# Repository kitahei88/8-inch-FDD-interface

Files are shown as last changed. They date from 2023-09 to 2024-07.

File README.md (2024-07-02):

# ANSI 8 inch Floppy Disk Drive adapter and Power board
---
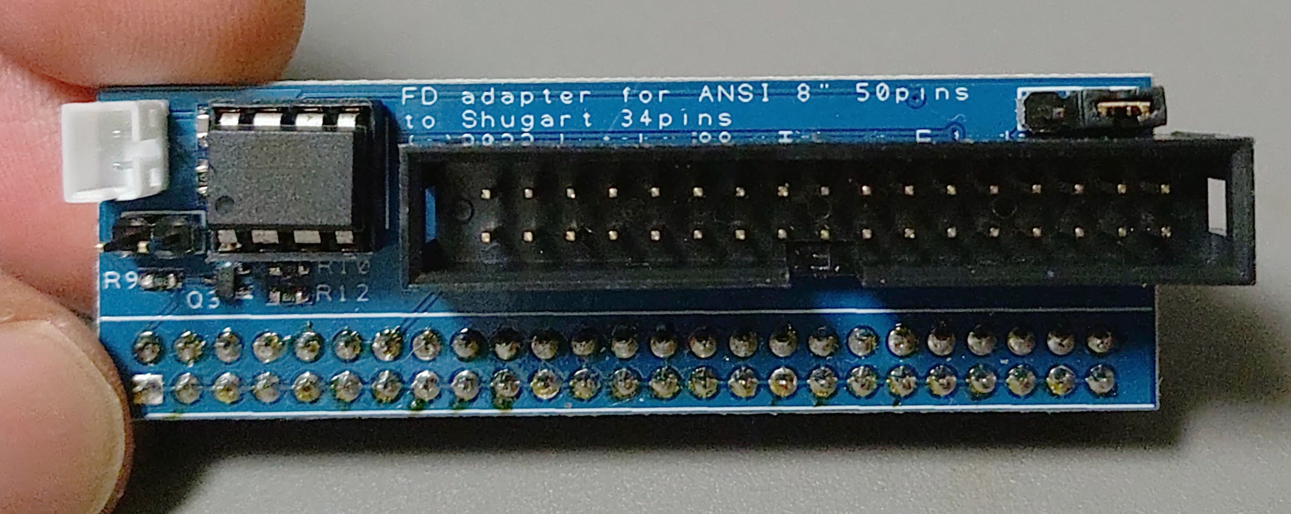
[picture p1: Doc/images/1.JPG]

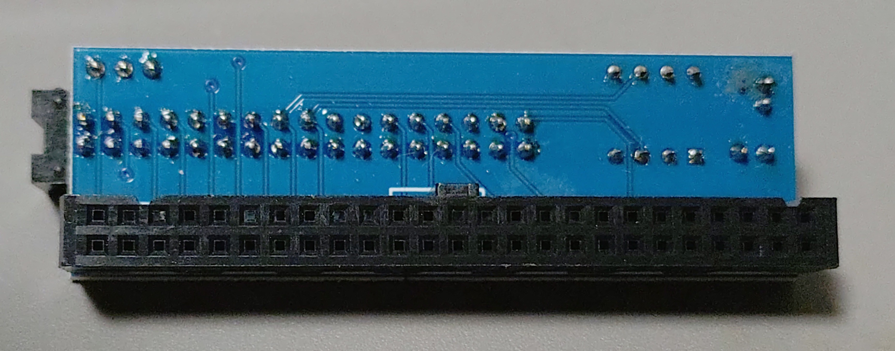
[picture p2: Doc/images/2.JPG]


This interface and power board is made for ANSI 8 inch interface drives and Pauline or any other FDD dump devices.
You can dump (or maybe write) 8 inch disk with this boards.
(And may be use with PC/AT machines that have FDD interfaces)

I tested NEC FD1165A and Pauline.

このインターフェースはANSI仕様の８インチドライブを通常の３４ピンコネクターに変換するものです。
このインターフェースを利用することで、Paulineやその他のフロッピーディスク読み出し環境で８インチディスクを読み込むことが可能となります。
ドライブに合わせたLowCurrent信号を作成することが出来ます。

NEC製のFD1165Aを利用して読み込み可能であることをテストしています。

Takuya Fukuda
Twitter: @kitahei88

License
This project is released under BSD 3-Clause License

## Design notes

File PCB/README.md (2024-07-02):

PCB was made with DesignSpark PCB Ver 10.0

Scheme is printed as PDF file.
Parts list is ODS file.

基板はDesignSpark PCB Ver10.0で作成しています。
gerberのフォルダにGerberとして出力しましています。それらをまとめたものもZIPファイルで置いてあります。
FusionPCBなどへ発注できると思います。

回路図はPDFファイルとしても参照可能です。
パーツリストは、ODSファイルに記載してあります。

The power supply board uses +24V DC power supply.
DC plug is an external diameter of 5.5 mm, an internal diameter of 2.1 mm, and a center-plus.
電源基板には+24Vの直流電源を使用します。
外形5.5mm、内径2.1mm、センタープラスのDCプラグで供給する形で作成しました。

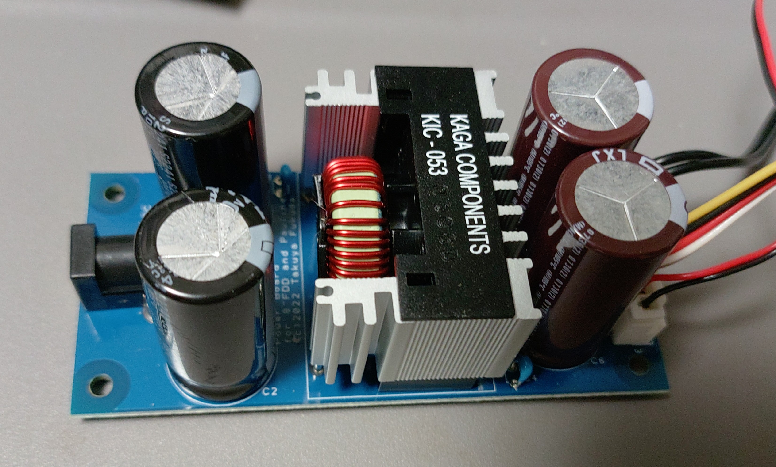
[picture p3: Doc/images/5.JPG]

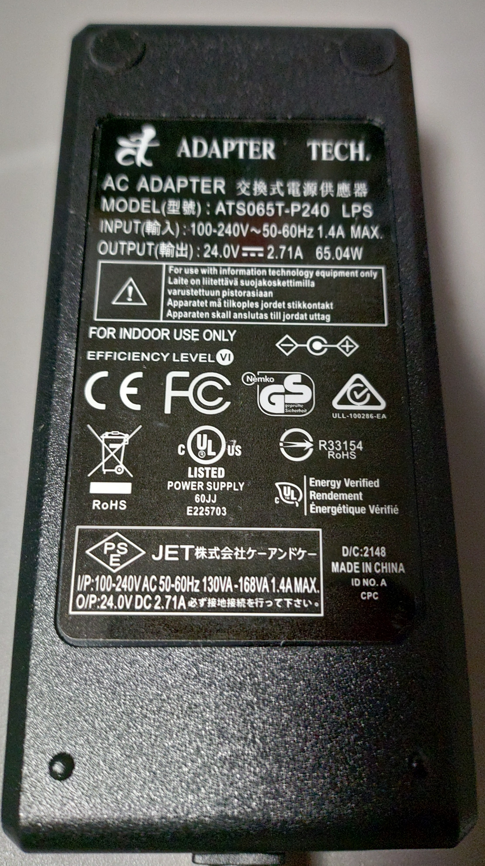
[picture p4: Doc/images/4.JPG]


The power outputs are XH 6pin connector for the 8" drive XH 2pin connector to supply power to the Pauline.
The output from each power supply pin is as shown in the image.

電源出力はXH6ピンが8インチドライブ用　XH2ピンがPaulineへの電源供給としています。
それぞれの電源ピンからの出力は画像に記載した通りです。

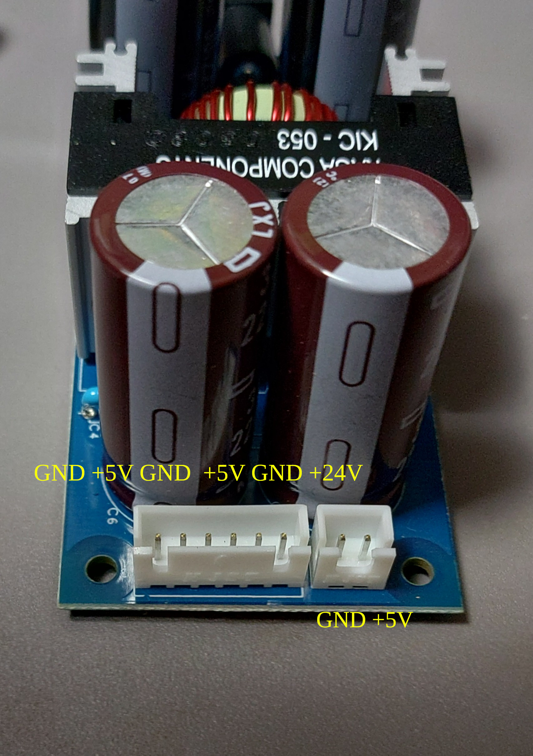
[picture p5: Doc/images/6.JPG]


One of the +5V from the XH6 pin feeds this interface board.
The interface side is made with a 2-pin PH connector.
The remaining +5V and +24V are supplied to the drive.
Refer to the data sheet of each drive for the connector to be supplied to the drive.

XH6ピンからの+5Vの一つはこのインターフェスに供給します。
インターフェス側はPHコネクターの2ピンのもので作成しています。
残りの+5V、+24Vはドライブへ供給します。
ドライブへのコネクターはそれぞれのドライブのデータシートなどを参考に供給してください。

NEC　FD1165Aの場合は、EIコネクターの7ピンで、
1pin +24V
2pin GND
3pin +5V
4pin GND
です。

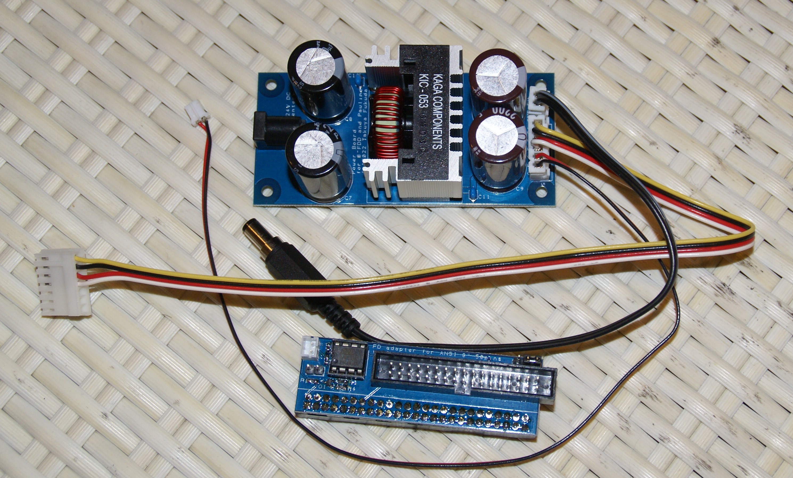
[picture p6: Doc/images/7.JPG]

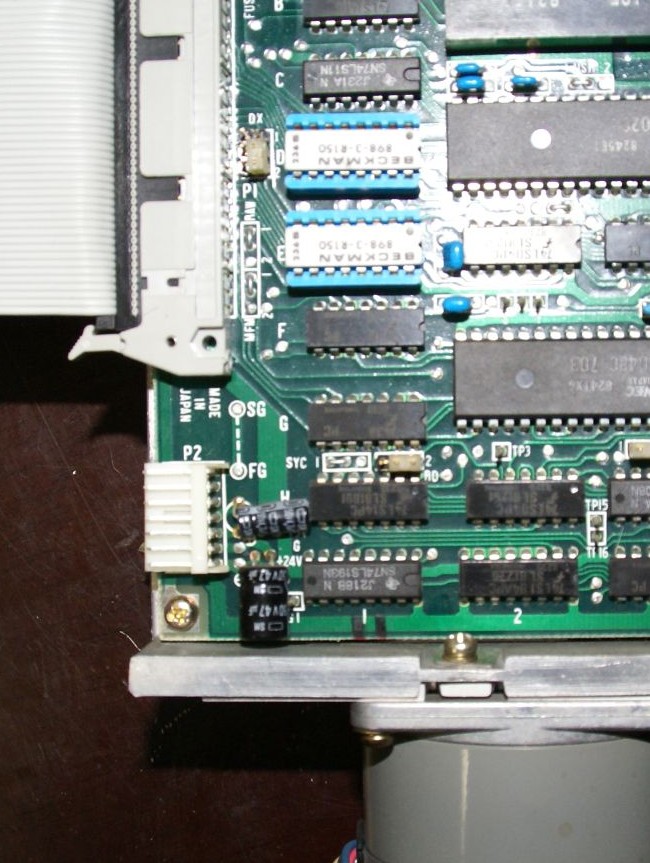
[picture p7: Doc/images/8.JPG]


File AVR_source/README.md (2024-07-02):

# AVR source and binary

This is microchip studio project file.
For Low current signal, you need to write bianry and set FUSE bits to AVR Attiny13A.

*Attention!!*

This project use Attiny13A Reset pin to GPIO.
It must be written in the following order.

1. Write main firmware(8ichlc.hex in ./avr_source_and_binary/8ichlc/Release/ ) to AVR.
2. Wrtie Low FUSE bit to 0x7A.
3. Write High FUSE bit to 0xFE.(Reset pin is disable)

And it cannot be re-written without AVR high voltage programmer.

AVRのソースとバイナリです。
Attiny13Aを使っています。（秋月などで購入）
ピンが少なく、リセットピンをI/Oとして使っていますので、書き込み方法に注意してください。

1. ファームウェア(./avr_source_and_binary/8ichlc/Release/にある 8ichlc.hex) をAVRに書き込む
2. Low FUSE を 0x7Aで書き込む
3. High FUSE を0xFEで書き込む.(リセットが出来なくなり、ISPで書き込めなくなります。)

消去や書き込みをする場合は　高電圧印加によるリセットが必要になります。

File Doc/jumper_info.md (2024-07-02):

# board jumper info

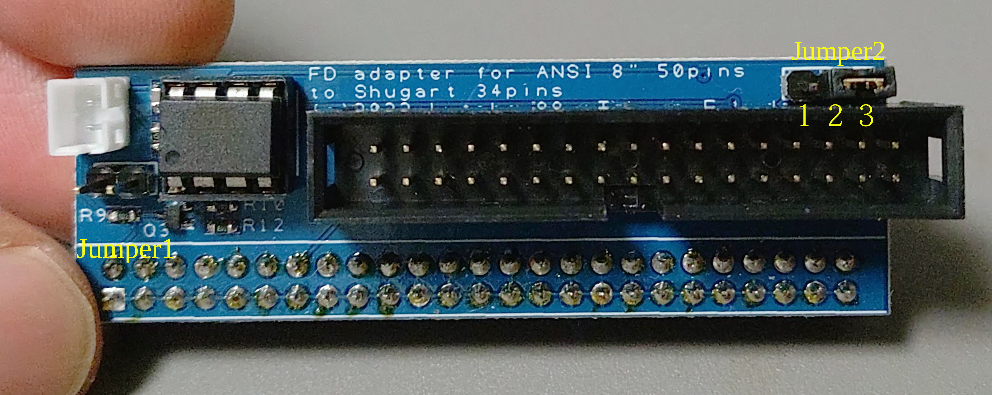
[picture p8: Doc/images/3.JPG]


## Jumper 1 
Select Drive model for Low current signal switching.
Short = YE data YE-180 1601
Open = NEC FD1165A

Low Currect信号の生成を機種によって変更するためのジャンパーです。
ショートするとYEデータのYE-180用となります
（low current はYEでは Write中の場合 　0〜43トラックでH 44〜76トラックでL。Read中は0〜59トラックでH 60〜76トラックでL）
オープンするとNEC　FD1165A用となります。
（NEC FD1165は、 read writeに関係なく0〜42トラックでH、43〜76トラックでL）

## Jumper 2
Select 34 pin signal (READY or DiskChange)
1-2 DiskChange (ANSI 8inch 12 pin to 34 pin)
2-3 READY (ANSI 8inch 22 pin to 34 pin)

通常の34ピンコネクターの34ピンにREADYかDiskChangeのどちらのラインを選択するかのジャンパーです。
1−2をショートするとDiskChangeが34ピンに接続されます
2−3をショートするとREADYが34ピンに接続されます

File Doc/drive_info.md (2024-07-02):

# Drive pin assign info

All odd pins are assigned to GND.

| Pin Number | FD1165A | YD-180 1601 |  YD-180 1600 | 
| --- | --- | --- | ---  |
| 2 | LOW CURRENT(i) | LOW CURRENT/SWITCH FILTER | Ready 3(o)|
| 4 | UNSAFE RESET(i) | Alternate I/O | Ready 2(o)|
| 6 | FILE UNSAFE(o) | Alternate I/O | Ready 1(o)|
| 8 | - | Alternate I/O |  SWITCH FILTER(i)|
| 10 | TWO SIDED(o) | TWO SIDED | DRIVE SELECT 3(i)|
| 12 | DISK CHANGE(o) | DISK CHANGE(optional) | DRIVE SELECT 2(i)|
| 14 | SIDE SELECT(i) | SIDE SELECT | DRIVE SELECT 1(i)|
| 16 | IN USE(i) | IN USE(optional) | DRIVE SELECT 0(i)|
| 18 | HEAD LOAD(i) | HEAD LOAD(optional) | HEAD LOAD(i)|
| 20 | INDEX(o) | INDEX | DIRECTION(i)|
| 22 | READY(o) | READY | STEP(i)|
| 24 | VFO SYNC(for VFO) | Alternate I/O | LOW CURRENT(i)|
| 26 | DRIVE SELECT 1(i) | DRIVE SELECT 1 | UNSAFE RESET(i)|
| 28 | DRIVE SELECT 2(i) | DRIVE SELECT 2 | TRACK 00(o)|
| 30 | DRIVE SELECT 3(i) | DRIVE SELECT 3 | WRITE PROTECT(o)|
| 32 | DRIVE SELECT 4(i) | DRIVE SELECT 4 | FILE UNSAFE(o)|
| 34 | DIRECTION SELECT(i) | DIRECTION | WRITE GATE(i)|
| 36 | STEP(i) | STEP |DRIVE SENCE(o)|
| 38 | WRITE DATA(i) | WRITE DATA |  WRITE DATA(i)|
| 40 | WRITE GATE(i) | WRITE GATE | INDEX(o)|
| 42 | TRACK 00 (o) | TRACK 00 | DISK2 SENSE(o)|
| 44 | WRITE PROTECT(o) | WRITE PROTECT | READY 0(o)|
| 46 | READ DATA  (o) | READ DATA |READ DATA(o)|
| 48 | MFM (for VFO) | - |  IN USE(i)|
| 50 | WINDOWS (for VFO)  | - |  HEAD SELECT(i)|

ドライブのピンアサインをまとめました。
奇数ピンはいずれのドライブもすべてGNDです。
カッコ内のiもしくはoはドライブ側からみた場合の信号入力、出力を意味しています。

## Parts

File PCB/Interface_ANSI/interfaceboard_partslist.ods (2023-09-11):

Position |  | parts
C1 | 0.1uF50V | RPEF11H104Z2P1A01B
R1 | 1kohm | 1/10W
R2 | 4k7ohm | 2/10W
R3 | 10kohm | 3/10W
R4 | 10kohm | 4/10W
Q1 | 2SC4116 | -Yor-GR
CONN1 | PH2 connector | B2B-PH-K-S
CONN2 | MIL board socket 50pin | OMRON XG4H-5031
CONN3 | MIL box plug 34pin | OMRON XG4C-3431
PL1 | jumper
PL2 | jumper

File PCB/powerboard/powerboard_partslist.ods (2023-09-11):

Position |  | parts
C1 | 3300uF50V | 50PX3300MEFC18X35.5
C2 | 3300uF50V | 50PX3300MEFC18X35.5
C3 | 0.1uF50V | RPEF11H104Z2P1A01B
C4 | 0.1uF50V | RPEF11H104Z2P1A01B
C5 | 220uF35V | 35ZLH220MEFC8X11.5
C6 | 220uF35V | 35ZLH220MEFC8X11.5
J1 |  | MJ-179PH
J2 |  | B2B-XH-A(LF)(SN)
J3 |  | B6B-XH-A(LF)(SN)
U1 |  | KIC-053

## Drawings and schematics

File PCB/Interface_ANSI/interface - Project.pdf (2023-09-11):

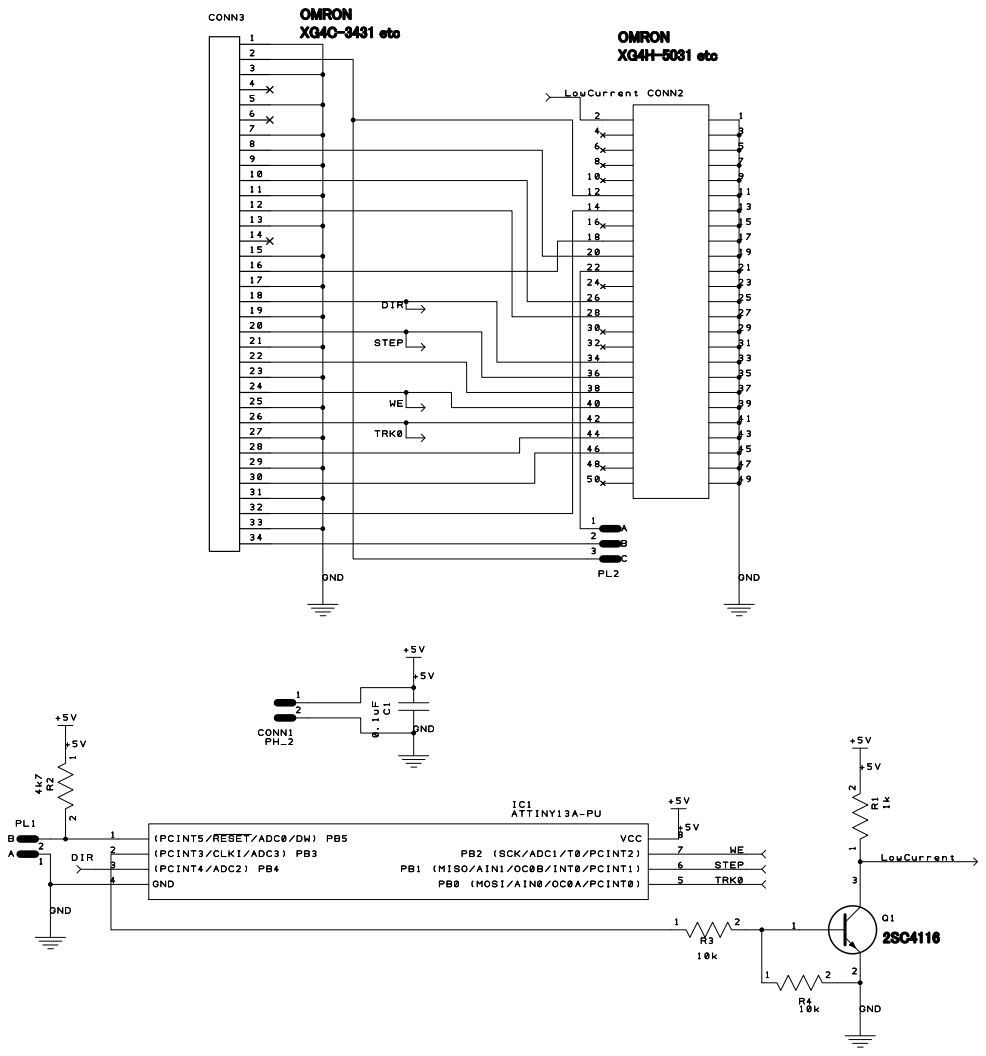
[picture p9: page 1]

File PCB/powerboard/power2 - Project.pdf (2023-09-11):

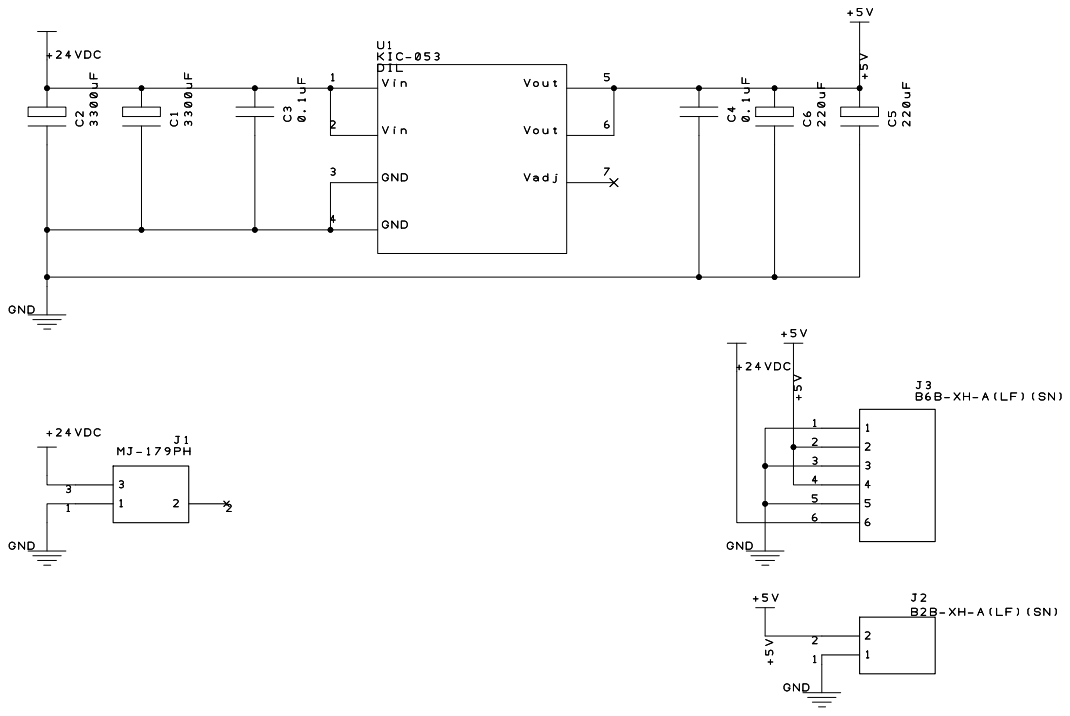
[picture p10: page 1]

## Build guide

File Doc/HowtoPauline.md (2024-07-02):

# How to use with Pauline

## Pauline Settings

Connect with a straight cable.
ストレートケーブルで接続します。

Set Pauline's Drive Script as follows
PaulineのDrive Scriptは以下のような設定にします。

```
set DRIVE_0_DESCRIPTION "8-inch Floppy drive"
set DRIVE_0_SELECT_LINE DRIVES_PORT_PIN10
set DRIVE_0_MOTOR_LINE  DRIVES_PORT_PIN16
set DRIVE_0_MAX_STEPS   76
```

The MOTOR signal is used for HEAD LOAD signal.
MOTOR信号でHEAD LOADの信号を賄うようにしています。

## FD1165A Setting

Jumper set as drive 1.
Turn off the VFO function. (RD jumper is set to the side of 2)
ジャンパーはドライブ１として設定
またVFOの機能は切っておきます。（RDのジャンパーは２の側へジャンパーを変更）

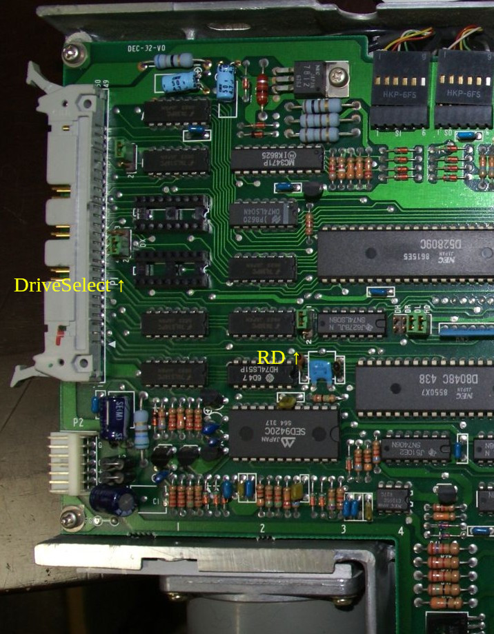
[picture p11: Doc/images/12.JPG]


## Connection

Attach the board to the drive.
ボードをドライブに取り付けます。

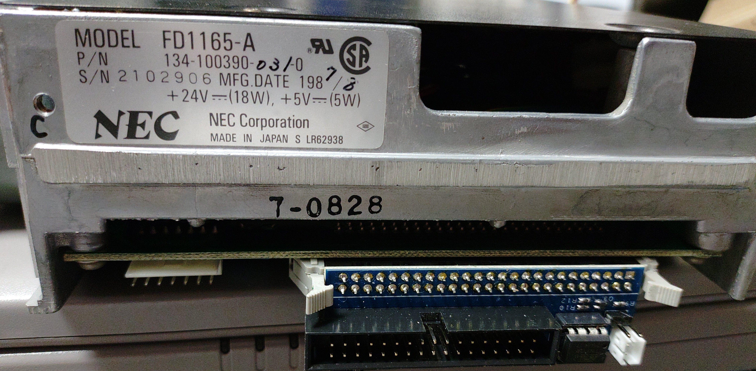
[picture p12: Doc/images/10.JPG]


Connect with a straight cable.
Power is supplied from the power supply board to the drive and Pauline.
ストレートケーブルで接続します。
電源基板から、ドライブ、Paulineへ電源供給します。

Dumping disk as usual.
後は通常通りPaulineで読み込みます。

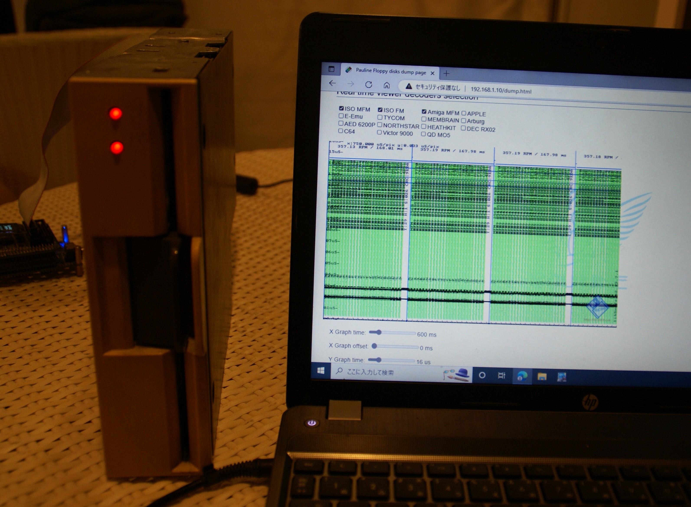
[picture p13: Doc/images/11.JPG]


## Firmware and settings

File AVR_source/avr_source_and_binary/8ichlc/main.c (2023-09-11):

/*
 * 8inchlc.c
 *
 * Created: 2022/08/30 
 *  Author: takuya fukuda
 *	8inch drive用　Low current信号生成
 *	***仕様***
 *	8inch ドライブに必要な low current 信号を自動で生成
 *	step, direction, track00, write gateを入力して low current を出力
 *	low current はYEでは Write中の場合 　0~43でH 44~76でLとし、Read中は0~59でH 60~76でL
 *	NEC FD1165は、 read writeに関係なく0~42でH、43~76でL
 *	Attiny13Aで作成
 *	pin数の関係でリセットを無効、GPIOとしている
 */ 

/*
	* FUSE bit(0 is enable)
	* 
	* Low 0x7A
	* SPIEN 0, EESAVE 1, WDTON 1, CKDIV8 1, SUT1:0 2'b01, CKSEL1:0 2'b10 ( internal RC Osc9.6MHz, statup 14ck+64ms)  
	* High 0xFE
	* BODLEVEL1:0 2'b11, DWEN 1, RSTBIDBL 0, SELFPRGEN 1;
	* Lock bit 0xFF means no lock 
*/

//#include <xc.h>
#include <avr/io.h>
#define F_CPU 9600000UL  // 9.6MHz internal clock
#include <util/delay.h>
#include <avr/interrupt.h>
#include "integer.h"

#define MAX_TRACK	76
#define YE	0
#define NEC	1
#define WR	0
#define RD	1

#define TRACK0		PINB0
#define	STEP		PINB1
#define WRITEGATE	PINB2
#define LOWCURRENT	PORTB3
#define DIRECTION	PINB4
#define MODEL		PINB5

#define EEPADD	0

/*	deprecated.h	*/
#define cbi(addr,bit) addr &= ~_BV(bit)	/* clear bit	*/
#define sbi(addr,bit) addr |= _BV(bit)	/* set bit		*/
#define ibi(addr,bit) addr ^= _BV(bit)	/* invert bit	*/ 

/*
	Step : INT0(PB1, pin6)
	Track00, write gate : PCINT0(Track00:PCINT0,PB0, pin5. write gate: PCINT2,PB2,pin 7.)
	direction: PB4,pin3 (Direction is low, head move to inner track,track number is up, high vise verse) 
	low current: PB3,pin2 (out)
	NEC and YE change: PB5(RST), select with jumper
*/

/* 	global valuable	*/ 
	CHAR	trk	 = 0;	// current track number
	CHAR	mode = YE;	// Drive model select
	CHAR	rw	 = RD;	// current read or write status

/*	global function	*/

void eeprom_write (unsigned char add, unsigned char dat)
{
	while(EECR & (1<<EEPE));
	EECR = (0<<EEPM1)|(0<<EEPM0);
	EEARL = add;
	EEDR = dat;
	EECR |= (1<<EEMPE);
	EECR |= (1<<EEPE);
}

unsigned char eeprom_read(unsigned char add)
{
	while(EECR & (1<<EEPE));
	EEARL = add;
	EECR |= (1<<EERE);
	return EEDR;	
}

/*	global function	end	*/
	
static inline
void init(void)
{
	cli();
	
	MCUCR	= 0x02;	/*	ISC1:0 = 2'b10, down trigger for INT0 */
	PCMSK	= 0x05;	/*	PCINT0 and PCINT2 is enable	*/
	PRR		= 0x03;	/*	Power Reduction setting (ADC disable, timer disable)	*/
	
	/* set PORTB I/O */
	DDRB	= 0b00001000;
	PORTB	= 0b00011111;
	// PB3 is out, other pins are input , pullup.
	
	GIMSK	= 0x60;	/*	INT0 and PCINT are enable	*/
  	sei();
	trk = eeprom_read(EEPADD);
}


ISR(INT0_vect)		// step signal is assert
{
	if ( bit_is_set(PINB,DIRECTION) ) // go to low track
		{	if (trk>0)  trk--;
		} else { // got high track
			if (trk<MAX_TRACK) trk++;
		}
	eeprom_write(EEPADD,trk);	
}

ISR(PCINT0_vect)	// Track00 or write gate is changed 
{ 
	if ( bit_is_set(PINB,WRITEGATE) )	rw = RD;
	if ( bit_is_clear(PINB,WRITEGATE) )	rw = WR;
	if ( bit_is_clear(PINB,TRACK0) )  {
		trk = 0;
		eeprom_write(EEPADD,trk);
		}
}


int main(void)
{
	init();
	if (bit_is_set(PINB,MODEL)) 	mode = NEC;
	
	while (1) {
		switch (mode)	{
			case NEC:
				if (trk<42) { PORTB &= ~(1<<LOWCURRENT);	// NPN tr switch, inverted out
					} else { PORTB |= (1<<LOWCURRENT);		// NPN tr switch, inverted out
					}
				break;
			case YE:
				if (rw == WR) {
					if (trk<44) { PORTB &= ~(1<<LOWCURRENT); 
						} else { PORTB |= (1<<LOWCURRENT);
						}
				} else {
					if (trk<60) { PORTB &= ~(1<<LOWCURRENT);
						} else { PORTB |= (1<<LOWCURRENT);
						}	
				}
				break;	
			default:
				break;
		}
	_delay_us(100);
	}
    return 0;
}
